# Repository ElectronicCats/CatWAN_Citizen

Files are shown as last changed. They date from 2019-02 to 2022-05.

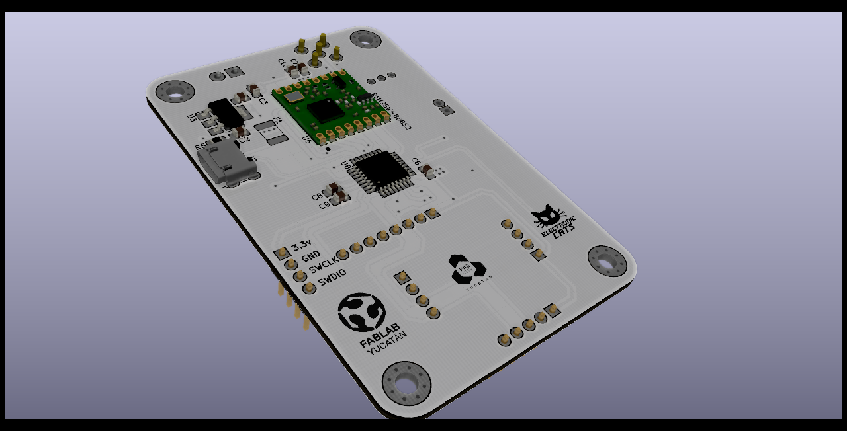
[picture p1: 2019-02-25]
Hardware/Citizen_Render_back.png

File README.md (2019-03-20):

# CatWAN Citizen Sensor Board

LoRa Smart city sensor, based on open hardware and free software, generating and sharing real open data on air pollution, acoustics and many more, compatible with LoRa and LoRaWAN.

## Sensor list

|Metric|Units|Sensor|
|-|:-:|:-:|
| **Atmospheric Pressure** | Pa | BME280 |
| **Air Temperature / Relative Humidity** | ºC / %rh | BME280|
| **CO, eCO2** | ppm |AMS CCS811|
| **Noise Level and Spectrum** | dBa |Microphone|
| **Ambient Light** | lx | Rohm BEML6075 |

## LICENSE
Firmware released under an GNU AGPL v3.0 license. See the LICENSE file for more information.

Hardware released under an CERN Open Hardware Licence v1.2. See the LICENSE_HARDWARE file for more information.

Designed by Electronic Cats.

Electronic Cats is a registered trademark, please do not use if you sell these PCBs.

Electronic Cats invests time and resources providing this open source design, please support Electronic Cats and open-source hardware by purchasing products from Electronic Cats!

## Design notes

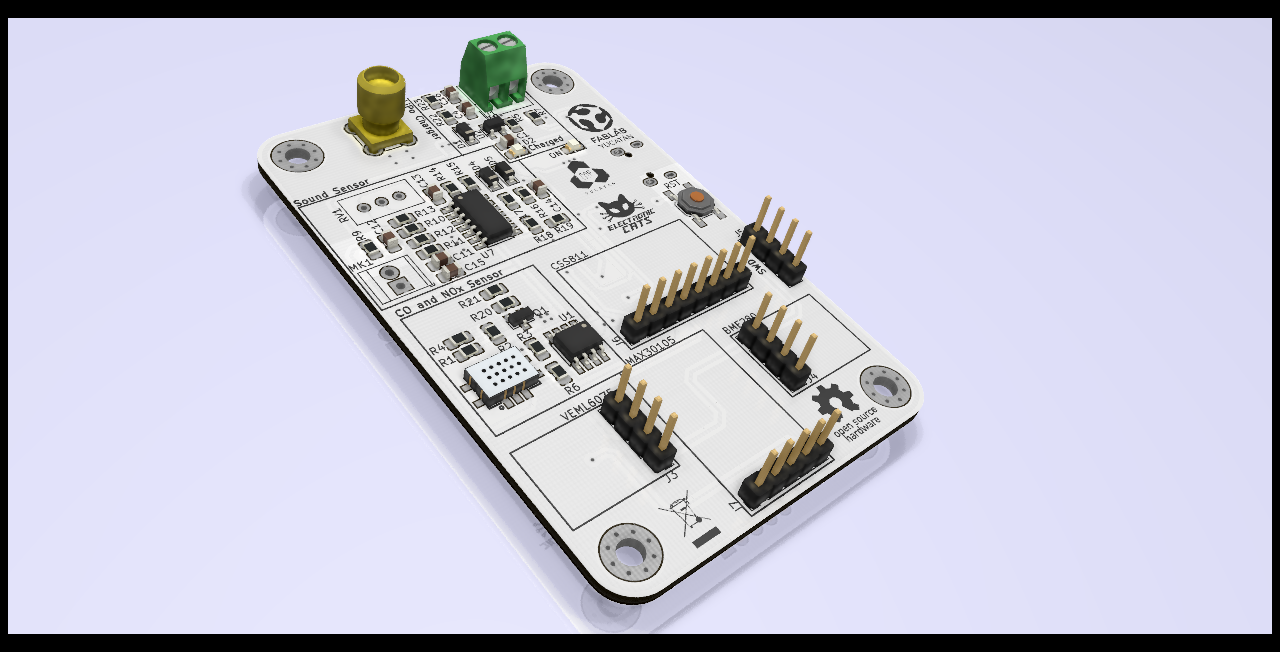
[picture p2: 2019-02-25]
Hardware/Citizen_Render_front.png

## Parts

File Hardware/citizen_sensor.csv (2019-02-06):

Item | Qty | Reference(s) | Value | manf#
1 | 1 | AE1 | Antenna_Shield | 977325
2 | 4 | C1, C2, C4, C5 | 10uf | 885012107004
3 | 5 | C3, C6, C7, C9,C15 | 0.1uf | 08056C104JAZ2A
4 | 3 | C8, C10, C11 | 1uf | CC0805KKX5R5BB105
5 | 2 | C12, C14 | 10uF | 885012107004
6 | 1 | C13 | 1uF | CC0805KKX5R5BB105
7 | 1 | D1 | D_Schottky | NRVB120VLSFT1G
8 | 1 | D2 | CHARGE | 150080VS75000
9 | 1 | D3 | ON | 150080SS75000
10 | 2 | D4, D5 | RB751S40T1G | NRVB120VLSFT1G
11 | 1 | F1 | Fuse | 0ZCG0030FF2C
13 | 1 | J2 | USB_B_Micro | 885012107004
17 | 1 | MK1 | Microphone | POM-3044P-R
18 | 1 | Q1 | 2N7002 | T2N7002AK,LM
19 | 2 | R1, R4 | 30 | CRCW080530R0FKEAC
20 | 1 | R2 | 36 | ERJ-6ENF36R0V
21 | 1 | R3 | 269 | ESR10EZPJ271
22 | 1 | R5 | 10k | ESR10EZPJ103
23 | 1 | R6 | 1 | RC0805FR-071R
24 | 2 | R7, R8 | 1k | ESR10EZPJ102
25 | 1 | R9 | 2.2K | RCG08052K20JNEA
26 | 2 | R10, R18 | 1K | ESR10EZPJ102
27 | 4 | R11, R12, R14, R17 | 10K | ESR10EZPJ103
28 | 1 | R13 | 100K | ERJ-6ENF1003V
29 | 1 | R15 | 22K | CRGP0805F22K
30 | 2 | R16, R19 | 100 | ESR10EZPJ101
31 | 1 | R20 | 66.5k | ERJ-6ENF6652V
32 | 1 | R21 | 66.5 | CRCW080566R5FKEA
33 | 1 | RV1 | 100K GAIN | 3362P-1-104LF
35 | 1 | U1 | TLC2272 | TLC2272CD
36 | 1 | U2 | MCP73831 | MCP73831T-5ACI/OT
37 | 1 | U3 | AP2114 | AP2114H-3.3TRG1
38 | 1 | U4 | MICS-4514 | MICS-4514
40 | 1 | U7 | LM324 | LM324DR
41 | 1 | U8 | ATSAMD21E18A-MU | ATSAMD21E15B-AUT

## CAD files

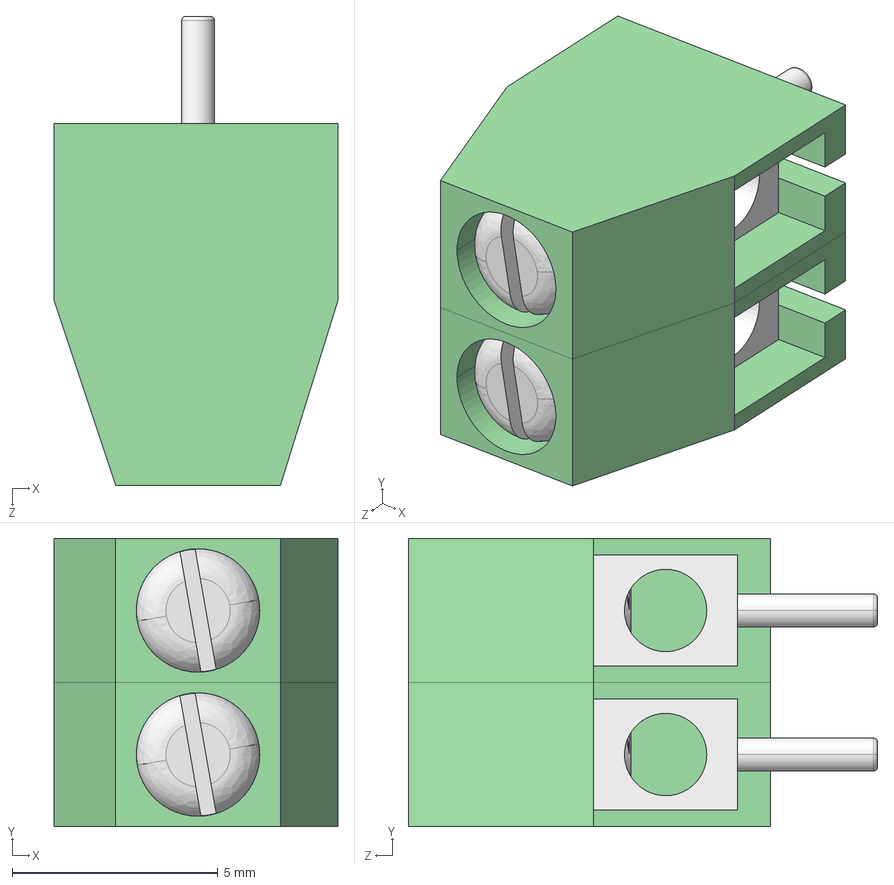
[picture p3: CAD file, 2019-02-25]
Hardware/3D/User Library-KF350-2P.STEP
6.90 x 7.00 x 11.4 mm
User Library-KF350-2P_KF850 Body x 2
User Library-KF350-2P_KF850 PIN x 2
User Library-KF350-2P_M2 Screw_91200A100 x 2

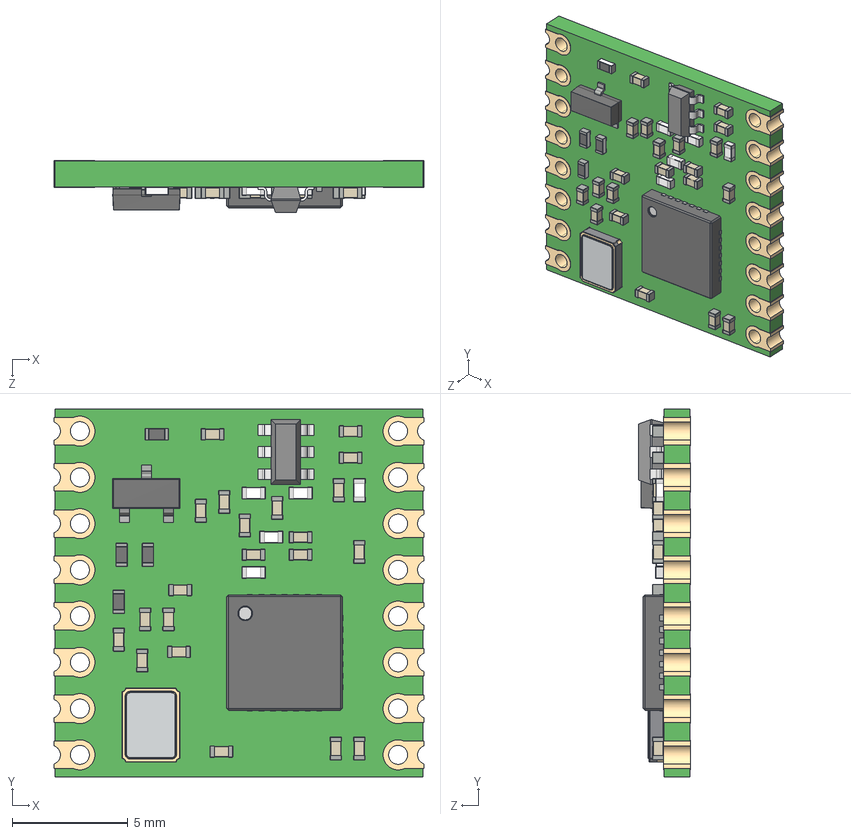
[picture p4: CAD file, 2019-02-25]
Hardware/3D/User Library-RFM96W.STEP
16.0 x 15.9 x 2.23 mm
User Library-RFM96W_Board
User Library-RFM96W_Cap0402 x 21
User Library-RFM96W_SW3dPS-inductor_0402_white x 5
User Library-RFM96W_SW3dPS-SOT-23-6
User Library-RFM96W_QFN28
User Library-RFM96W_TXC_7M
User Library-RFM96W_Res0402 x 4
User Library-RFM96W_User_Library-3-lead_sot23-3
User Library-RFM96W_Goldcontact x 16

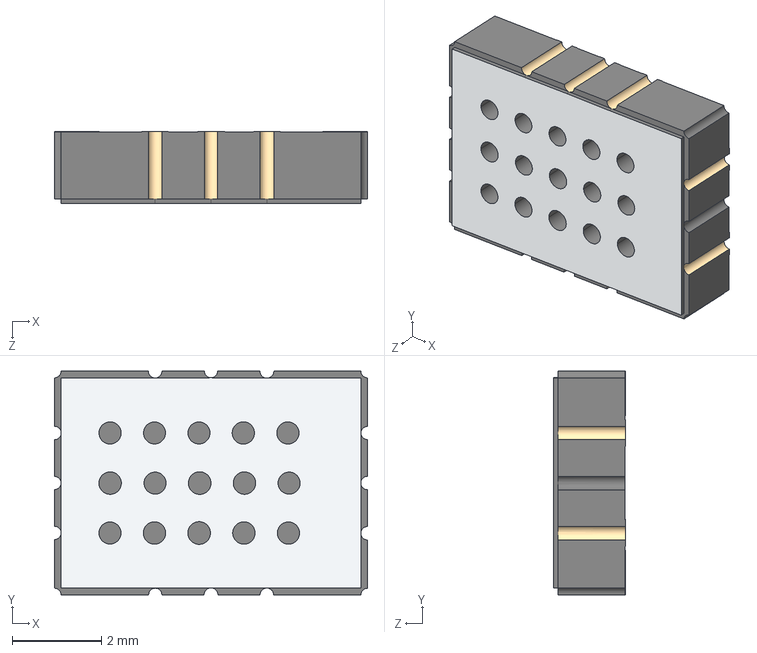
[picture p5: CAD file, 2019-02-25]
Hardware/3D/MICS-4514.STEP
7.00 x 5.00 x 1.61 mm

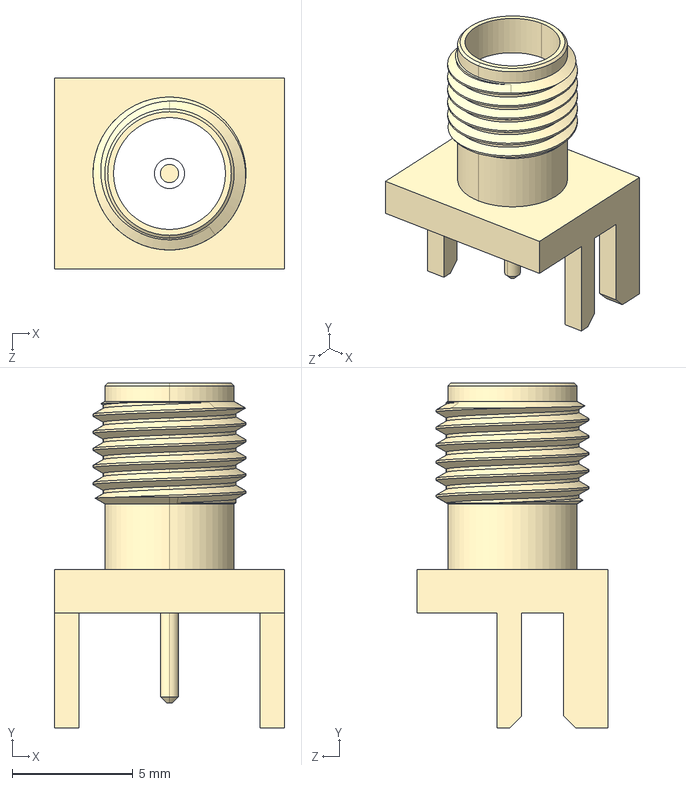
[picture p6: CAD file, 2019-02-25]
Hardware/3D/User Library-Johnson Components SMA - 50 Ohm Connectors 142-0701-801.STEP
9.52 x 14.3 x 7.92 mm

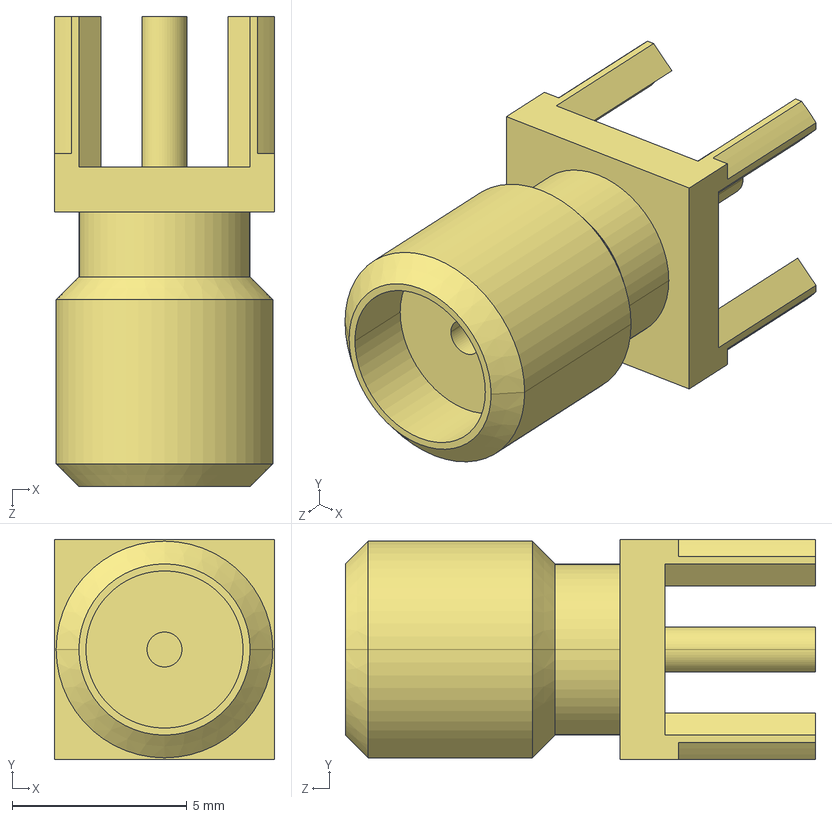
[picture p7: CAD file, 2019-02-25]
Hardware/3D/sma.STEP
6.31 x 6.31 x 13.4 mm

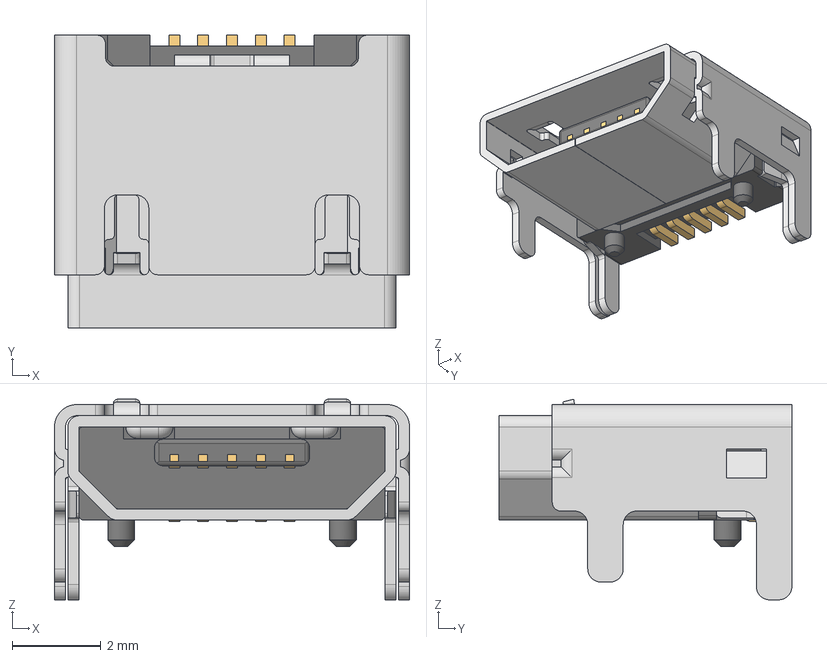
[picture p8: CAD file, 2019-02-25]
Hardware/3D/629105150521 (rev1).stp
8.00 x 6.60 x 4.52 mm
629105150521_Housing
629105150521_Pin1 x 4
629105150521_Pin2
629105150521_Shielding2
629105150521_Shielding

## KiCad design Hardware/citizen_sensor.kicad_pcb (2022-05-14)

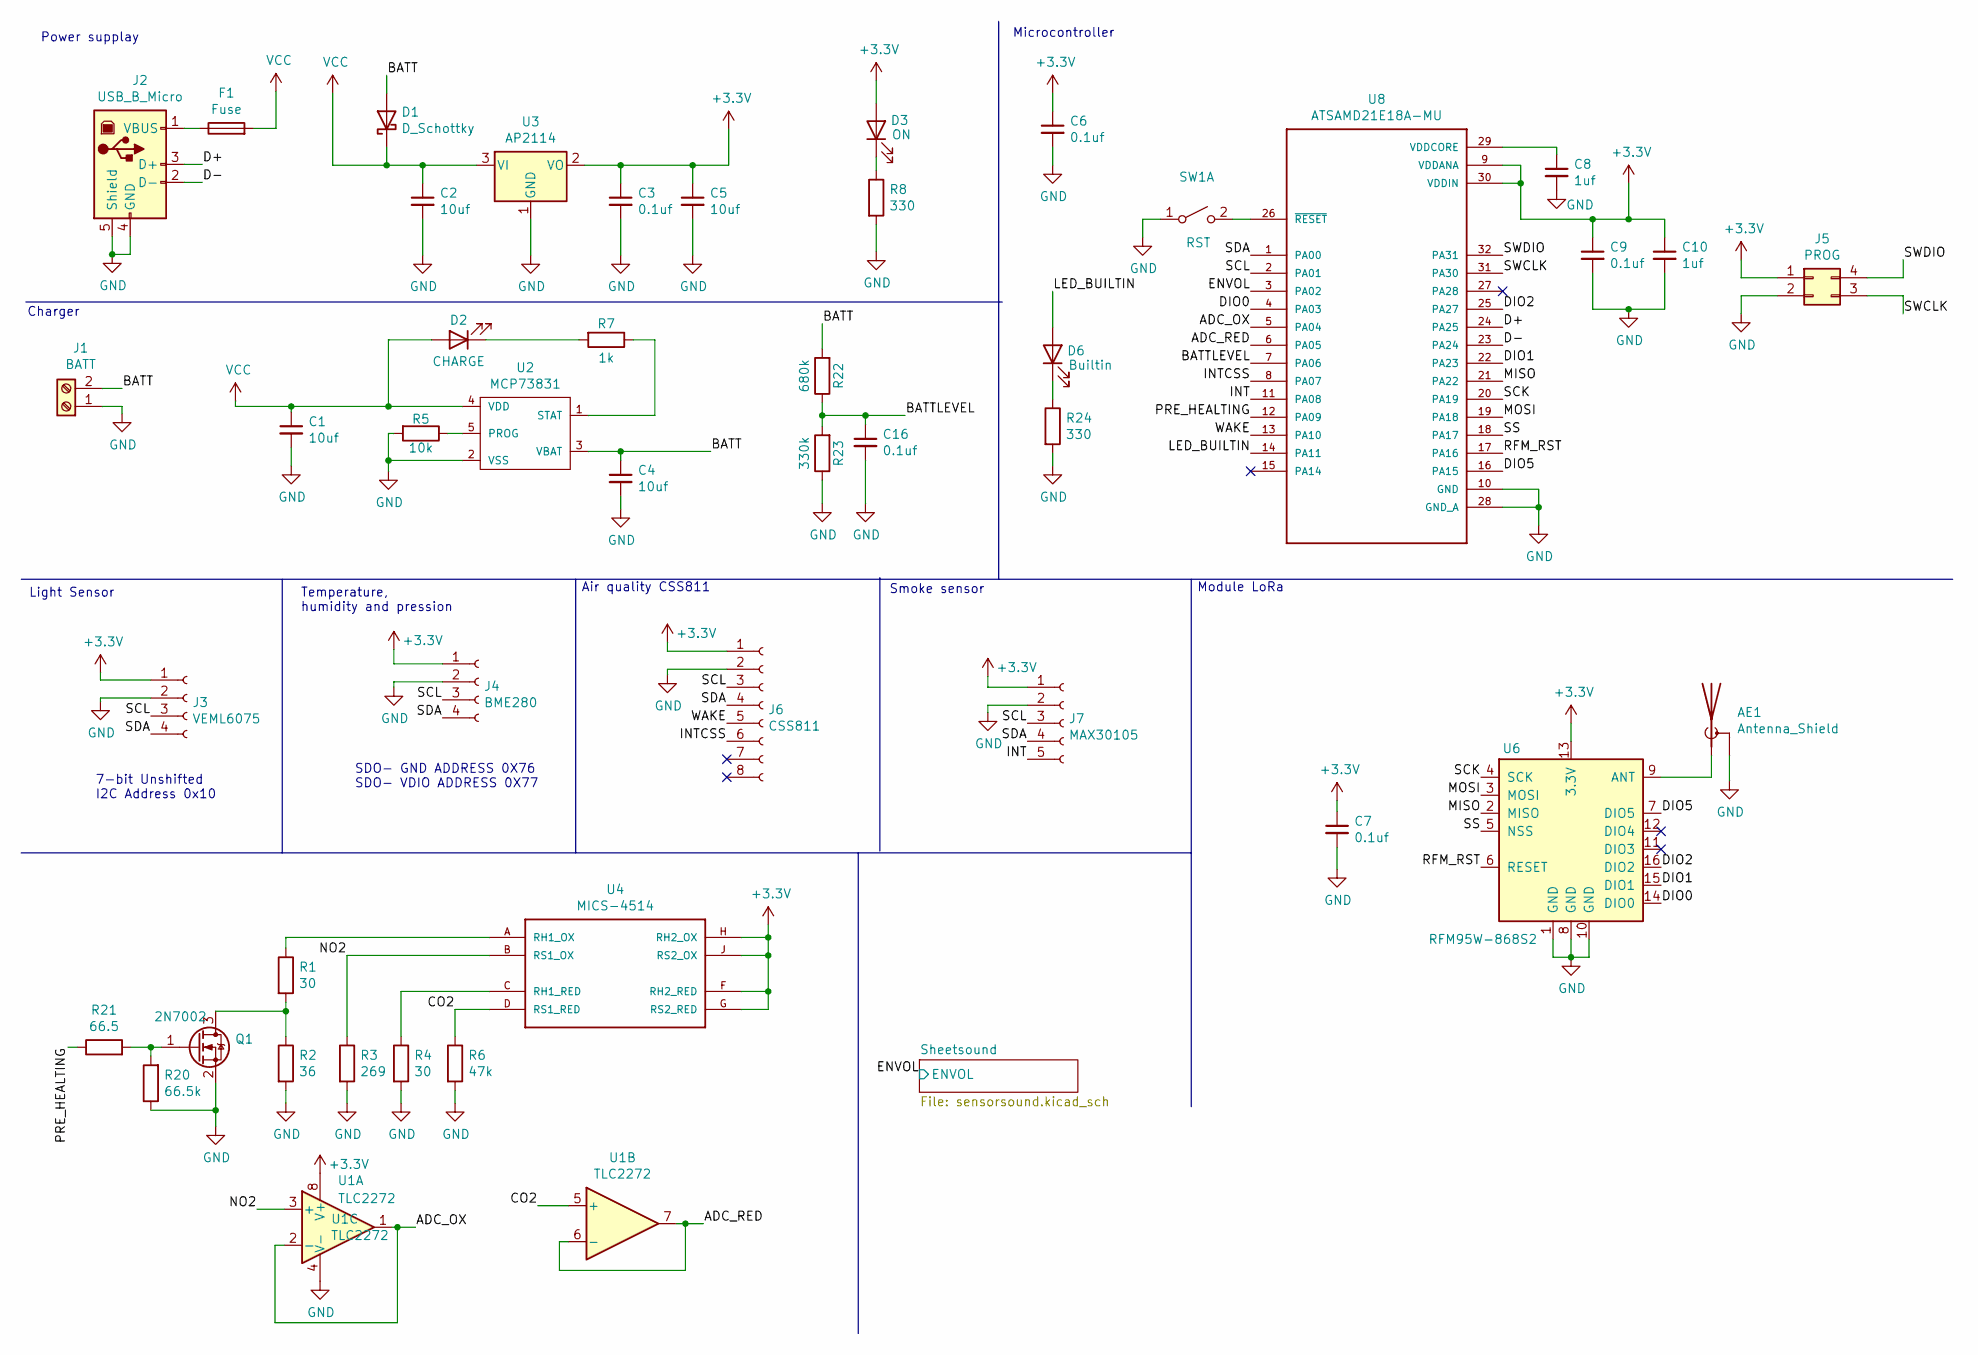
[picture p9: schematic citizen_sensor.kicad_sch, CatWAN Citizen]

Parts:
AE1: Antenna_Shield; AMPHENOL_901-144
C1, C2, C4, C5: 10uf; C_0805_2012Metric_Pad1.15x1.40mm_HandSolder
C3, C6, C7, C9, C16: 0.1uf; C_0805_2012Metric_Pad1.15x1.40mm_HandSolder
C8, C10: 1uf; C_0805_2012Metric_Pad1.15x1.40mm_HandSolder
D1: D_Schottky; D_SOD-123
D2: CHARGE; LED_0805_2012Metric_Castellated
D3: ON; LED_0805_2012Metric_Castellated
D6: Builtin; LED_0805_2012Metric_Castellated
F1: Fuse; Fuse_1812_4532Metric_Pad1.30x3.40mm_HandSolder
J1: BATT; TerminalBlock_4Ucon_1x02_P3.50mm_Vertical
J2: USB_B_Micro; USB_Micro-B_Wuerth_629105150521
J3: VEML6075; PinHeader_1x04_P2.54mm_Vertical
J4: BME280; PinHeader_1x04_P2.54mm_Vertical
J5: PROG; PinHeader_1x04_P2.54mm_Vertical
J6: CSS811; PinHeader_1x08_P2.54mm_Vertical
J7: MAX30105; PinHeader_1x05_P2.54mm_Vertical
Q1: 2N7002; SOT-23
R1, R4: 30; R_0805_2012Metric_Pad1.15x1.40mm_HandSolder
R2: 36; R_0805_2012Metric_Pad1.15x1.40mm_HandSolder
R3: 269; R_0805_2012Metric_Pad1.15x1.40mm_HandSolder
R5: 10k; R_0805_2012Metric_Pad1.15x1.40mm_HandSolder
R6: 47k; R_0805_2012Metric_Pad1.15x1.40mm_HandSolder
R7: 1k; R_0805_2012Metric_Pad1.15x1.40mm_HandSolder
R8, R24: 330; R_0805_2012Metric_Pad1.15x1.40mm_HandSolder
R20: 66.5k; R_0805_2012Metric_Pad1.15x1.40mm_HandSolder
R21: 66.5; R_0805_2012Metric_Pad1.15x1.40mm_HandSolder
R22: 680k; R_0805_2012Metric_Pad1.15x1.40mm_HandSolder
R23: 330k; R_0805_2012Metric_Pad1.15x1.40mm_HandSolder
SW1: RST; SW_SPST_TL3342
U1: TLC2272; SOIC-8_3.9x4.9mm_P1.27mm
U2: MCP73831; SOT-23-5
U3: AP2114; SOT-223-3_TabPin2
U4: MICS-4514; MICS_10-SMD
U6: RFM95W-868S2; RFM95W
U8: ATSAMD21E18A-MU; TQFP-32_7x7mm_P0.8mm

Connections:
+3V3: C3.1, C5.1, C6.1, C7.1, C9.1, C10.1, D3.2 (A), J3.1, J4.1, J5.1, J6.1, J7.1, U1.8 (V+), U3.2 (VO), U4.F (RH2_RED), U4.G (RS2_RED), U4.H (RH2_OX), U4.J (RS2_OX), U6.13 (3.3V), U8.9 (VDDANA), U8.30 (VDDIN); also elsewhere on the board
/ADC_OX: U1.1, U1.2 (-), U8.5 (PA04)
/ADC_RED: U1.6 (-), U1.7, U8.6 (PA05)
/BATT: C4.1, D1.2 (A), J1.2, R22.2, U2.3 (VBAT)
/BATTLEVEL: C16.1, R22.1, R23.2, U8.7 (PA06)
/CO2: R6.1, U1.5 (+), U4.D (RS1_RED)
/D+: J2.3 (D+), U8.24 (PA25)
/D-: J2.2 (D-), U8.23 (PA24)
/DIO0: U6.14 (DIO0), U8.4 (PA03)
/DIO1: U6.15 (DIO1), U8.22 (PA23)
/DIO2: U6.16 (DIO2), U8.25 (PA27)
/DIO5: U6.7 (DIO5), U8.16 (PA15)
/ENVOL: U8.3 (PA02); also elsewhere on the board
/INT: J7.5, U8.11 (PA08)
/INTCSS: J6.6, U8.8 (PA07)
/LED_BUILTIN: D6.2 (A), U8.14 (PA11)
/MISO: U6.2 (MISO), U8.21 (PA22)
/MOSI: U6.3 (MOSI), U8.19 (PA18)
/NO2: R3.1, U1.3 (+), U4.B (RS1_OX)
/PRE_HEALTING: R21.1, U8.12 (PA09)
/RFM_RST: U6.6 (RESET), U8.17 (PA16)
/SCK: U6.4 (SCK), U8.20 (PA19)
/SCL: J3.3, J4.3, J6.3, J7.3, U8.2 (PA01)
/SDA: J3.4, J4.4, J6.4, J7.4, U8.1 (PA00)
/SS: U6.5 (NSS), U8.18 (PA17)
/SWCLK: J5.3, U8.31 (PA30)
/SWDIO: J5.4, U8.32 (PA31)
/WAKE: J6.5, U8.13 (PA10)
GND: AE1.2 (Shield), C1.2, C2.2, C3.2, C4.2, C5.2, C6.2, C7.2, C8.2, C9.2, C10.2, C16.2, J1.1, J2.4 (GND), J2.5 (Shield), J3.2, J4.2, J5.2, J6.2, J7.2, Q1.2 (S), R2.2, R3.2, R4.2, R5.2, R6.2, R8.2, R20.1, R23.1, R24.2, SW1.1 (A), U1.4 (V-), U2.2 (VSS), U3.1 (GND), U6.1 (GND), U6.8 (GND), U6.10 (GND), U8.10 (GND), U8.28 (GND_A); also elsewhere on the board
unnamed: AE1.1 (A), U6.9 (ANT)
unnamed: C8.1, U8.29 (VDDCORE)
unnamed: D2.1 (K), R7.2
unnamed: D3.1 (K), R8.1
unnamed: D6.1 (K), R24.1
unnamed: F1.1, J2.1 (VBUS)
unnamed: Q1.1 (G), R20.2, R21.2
unnamed: Q1.3 (D), R1.2, R2.1
unnamed: R1.1, U4.A (RH1_OX)
unnamed: R4.1, U4.C (RH1_RED)
unnamed: R5.1, U2.5 (PROG)
unnamed: R7.1, U2.1 (STAT)
unnamed: SW1.2 (B), U8.26 (~RESET)
VCC: C1.1, C2.1, D1.1 (K), D2.2 (A), F1.2, U2.4 (VDD), U3.3 (VI)

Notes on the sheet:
Module LoRa
Microcontroller
Air quality CSS811
Smoke sensor
Power supplay
7-bit Unshifted I2C Address 0x10
Charger
Light Sensor
Temperature, humidity and pression
SDO- GND ADDRESS 0X76 SDO- VDIO ADDRESS 0X77

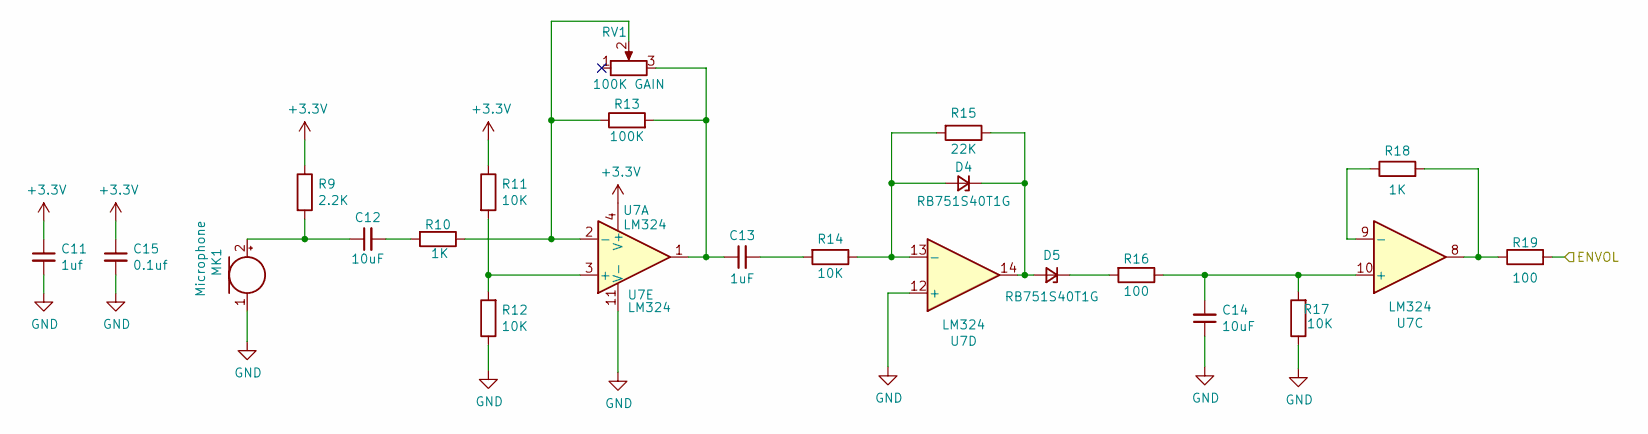
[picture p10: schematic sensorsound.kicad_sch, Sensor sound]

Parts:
C11: 1uf; C_0805_2012Metric_Pad1.15x1.40mm_HandSolder
C12, C14: 10uF; C_0805_2012Metric_Pad1.15x1.40mm_HandSolder
C13: 1uF; C_0805_2012Metric_Pad1.15x1.40mm_HandSolder
C15: 0.1uf; C_0805_2012Metric_Pad1.15x1.40mm_HandSolder
D4, D5: RB751S40T1G; D_SOD-123
MK1: Microphone; TerminalBlock_TE_282834-2_1x02_P2.54mm_Horizontal
R9: 2.2K; R_0805_2012Metric_Pad1.15x1.40mm_HandSolder
R10, R18: 1K; R_0805_2012Metric_Pad1.15x1.40mm_HandSolder
R11, R12, R14, R17: 10K; R_0805_2012Metric_Pad1.15x1.40mm_HandSolder
R13: 100K; R_0805_2012Metric_Pad1.15x1.40mm_HandSolder
R15: 22K; R_0805_2012Metric_Pad1.15x1.40mm_HandSolder
R16, R19: 100; R_0805_2012Metric_Pad1.15x1.40mm_HandSolder
RV1: 100K GAIN; Potentiometer_Bourns_3386P_Vertical
U7: LM324; SOIC-14_3.9x8.7mm_P1.27mm

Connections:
+3V3: C11.1, C15.1, R9.1, R11.1, U7.4 (V+); also elsewhere on the board
/ENVOL: R19.2; also elsewhere on the board
GND: C11.2, C14.1, C15.2, MK1.1 (-), R12.1, R17.1, U7.11 (V-), U7.12 (+); also elsewhere on the board
unnamed: C12.1, MK1.2 (+), R9.2
unnamed: C12.2, R10.2
unnamed: C13.1, R13.2, RV1.3, U7.1
unnamed: C13.2, R14.2
unnamed: C14.2, R16.1, R17.2, U7.10 (+)
unnamed: D4.1 (K), D5.2 (A), R15.1, U7.14
unnamed: D4.2 (A), R14.1, R15.2, U7.13 (-)
unnamed: D5.1 (K), R16.2
unnamed: R10.1, R13.1, RV1.2, U7.2 (-)
unnamed: R11.2, R12.2, U7.3 (+)
unnamed: R18.1, U7.9 (-)
unnamed: R18.2, R19.1, U7.8

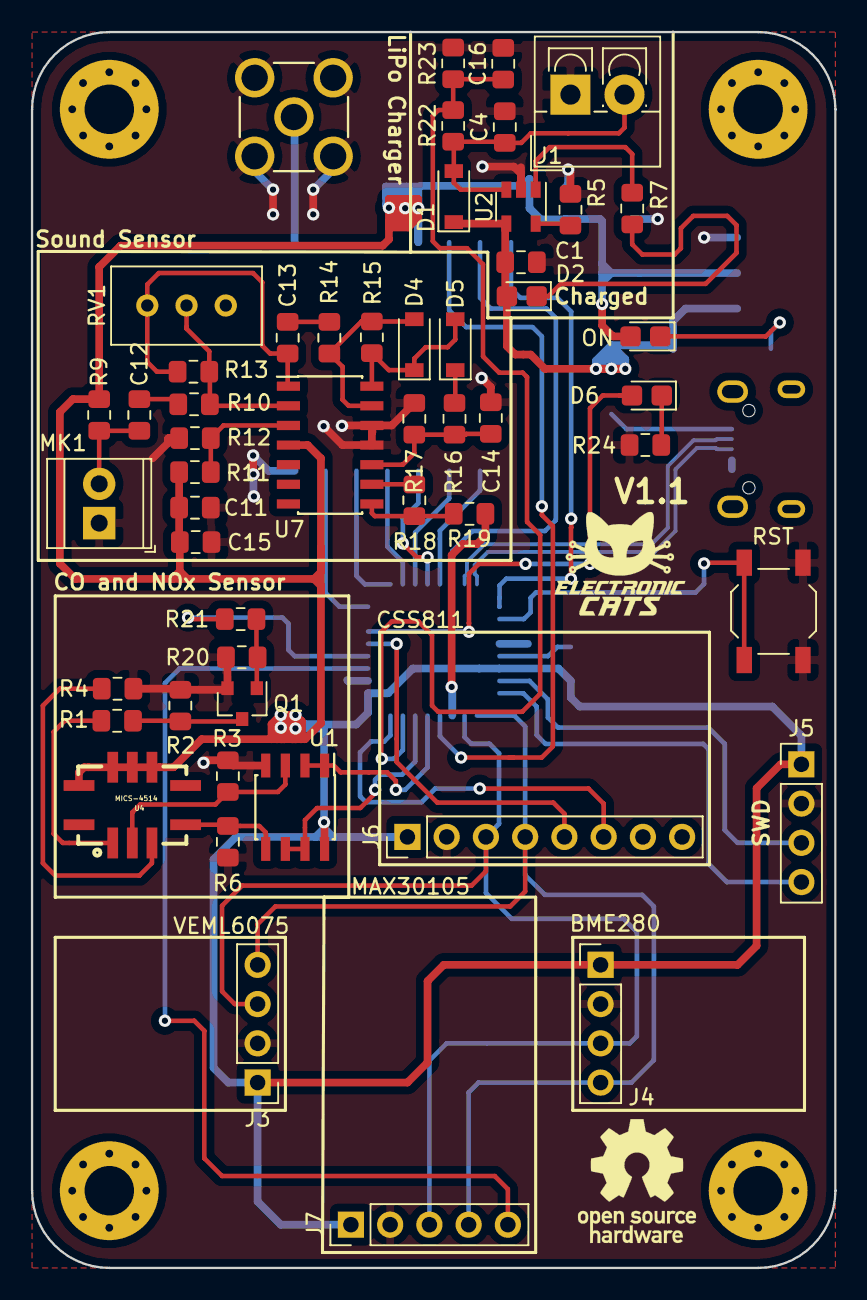
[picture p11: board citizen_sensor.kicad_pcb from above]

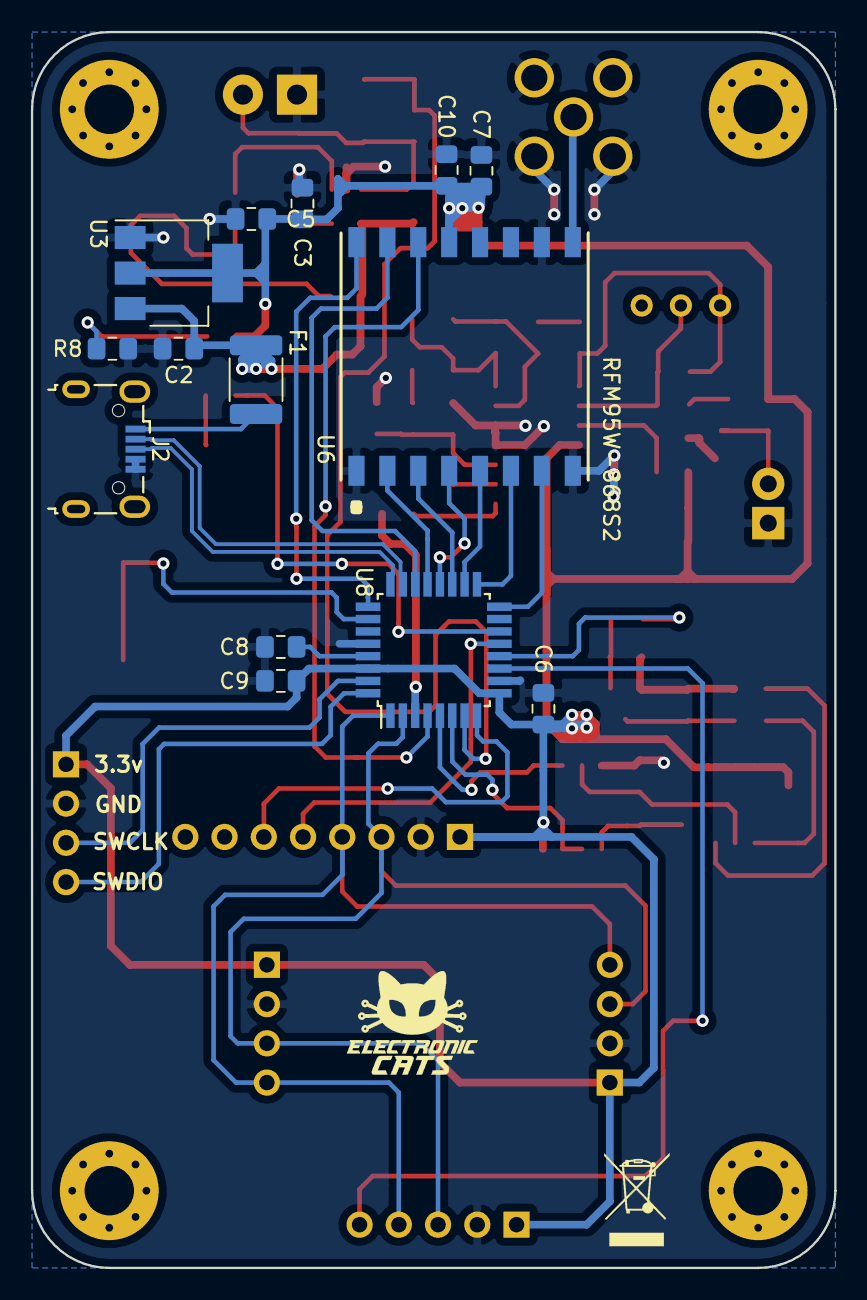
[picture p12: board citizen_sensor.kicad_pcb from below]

Board: 2 copper layers, 52.0 x 80.0 mm, 66 parts (14 on the bottom side), 55 nets.

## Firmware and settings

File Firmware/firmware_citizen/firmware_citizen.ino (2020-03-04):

/*******************************************************************************
  Created by: Eduardo Contreras @ Electronic Cats 2019
              Rocio Rodriguez @ Electronic Cats 2019
              Andres Sabas @ Electronic Cats 2020
 
  Example for the CITIZEN board
    In this example you can send:
    TEMPERATURE, HUMINIDY AND PRESSURE sensor information read by the BME280 
    CO and NO2 levels sensor informationread by the MICS4514 
    CO2 levels sensor information read by the CSS811 
    VEML6075
    Sound Sensor embedded
    
  Example
 *******************************************************************************/
#include <lorawan.h>
#include <CayenneLPP.h>
#include <Wire.h>
#include "Adafruit_CCS811.h"
#include "SparkFunBME280.h"
#include <SparkFun_VEML6075_Arduino_Library.h>

#define _USE_BME_
#define _USE_CSS_
#define _USE_MICS_
#define _USE_VME_
//#define _USE_SOUND_
//#define DEBUG

#ifdef _USE_BME_ 
  BME280 BME; 
#endif

#ifdef _USE_CSS_ //pregunta si de definio el sensor CCS811
  Adafruit_CCS811 ccs;
#endif

#ifdef _USE_VME_ 
  VEML6075 uv; 
  // Calibration constants:
  // Four gain calibration constants -- alpha, beta, gamma, delta -- can be used to correct the output in
  // reference to a GOLDEN sample. The golden sample should be calibrated under a solar simulator.
  // Setting these to 1.0 essentialy eliminates the "golden"-sample calibration
  const float CALIBRATION_ALPHA_VIS = 1.0; // UVA / UVAgolden
  const float CALIBRATION_BETA_VIS  = 1.0; // UVB / UVBgolden
  const float CALIBRATION_GAMMA_IR  = 1.0; // UVcomp1 / UVcomp1golden
  const float CALIBRATION_DELTA_IR  = 1.0; // UVcomp2 / UVcomp2golden

  // Responsivity:
  // Responsivity converts a raw 16-bit UVA/UVB reading to a relative irradiance (W/m^2).
  // These values will need to be adjusted as either integration time or dynamic settings are modififed.
  // These values are recommended by the "Designing the VEML6075 into an application" app note for 100ms IT
  const float UVA_RESPONSIVITY = 0.00110; // UVAresponsivity
  const float UVB_RESPONSIVITY = 0.00125; // UVBresponsivity

  // UV coefficients:
  // These coefficients
  // These values are recommended by the "Designing the VEML6075 into an application" app note
  const float UVA_VIS_COEF_A = 2.22; // a
  const float UVA_IR_COEF_B  = 1.33; // b
  const float UVB_VIS_COEF_C = 2.95; // c
  const float UVB_IR_COEF_D  = 1.75; // d
#endif

#ifdef _USE_SOUND_ 
#define N 5
  float filtered;
  float vals[N];

  const double dBAnalogQuiet = 10; // envelope - calibrated value from analog input (48 dB equivalent)
  const double dBAnalogModerate = 15;
  const double dBAnalogLoud = 30;
  int count;

float calculateDecibels(int x, char c)
{
  float decibelsCalculated;
  
    if (c == 'q')
      decibelsCalculated = 20 * log10(x/dBAnalogQuiet);
    if (c == 'm')
      decibelsCalculated = 20 * log10(x/dBAnalogModerate);
    if (c == 'l')
      decibelsCalculated = 20 * log10(x/dBAnalogLoud);  
      
  return (decibelsCalculated);
}
#endif

CayenneLPP lpp(51);

//ABP Credentials 
const char *devAddr = "00000000";
const char *nwkSKey = "00000000000000000000000000000000";
const char *appSKey = "00000000000000000000000000000000";

unsigned long previousMillis = 0;  // will store last time message sent
const unsigned long interval = 30000;    // 10 s interval to send message

// Pin mapping for RFM9X
const sRFM_pins RFM_pins = {
  .CS = SS,
  .RST = RFM_RST,
  .DIO0 = RFM_DIO0,
  .DIO1 = RFM_DIO1,
  .DIO2 = RFM_DIO2,
  .DIO5 = RFM_DIO5,
};


void setup() {
  Serial.begin(115200);
  #ifdef DEBUG
    while(!Serial);
  #endif
  Serial.println(F("[INFO] LoRa Demo Node 1 Demonstration"));

   if(!lora.init()){
    Serial.println("RFM95 not detected");
    delay(5000);
    return;
  }
  
  #ifdef _USE_BME_
  Wire.begin();
  BME.setI2CAddress(0x76); //Connect to a second sensor
  if(BME.beginI2C() == false) Serial.println("Sensor BME280 connect failed");
  #endif

  #ifdef _USE_CSS_
  Serial.println("[INFO] CCS811 in use");
  pinMode(10, OUTPUT);
  digitalWrite(10, LOW);
  
  if(!ccs.begin()){
    Serial.println("[INFO] Failed to start sensor CSS811! Please check your wiring.");
    while(1);
    //calibrate temperature sensor
    while(!ccs.available());
    float temp = ccs.calculateTemperature();
    ccs.setTempOffset(temp - 25.0);
  }
  #endif

  #ifdef _USE_MICS_
  pinMode(9,OUTPUT);
  analogReadResolution(12);
  Serial.println("[INFO] Pre heating MICS");
  digitalWrite(9, HIGH);
  Serial.println("[INFO] heating MICS");
  Serial.println("[INFO] Pre heating done MICS");
  digitalWrite(9, LOW);
  #endif

    #ifdef _USE_VME_
  if (!uv.begin())
  {
    Serial.println("Unable to communicate with VEML6075.");
    while (1);
  }

  // Integration time and high-dynamic values will change the UVA/UVB sensitivity. That means
  // new responsivity values will need to be measured for every combination of these settings.
  uv.setIntegrationTime(VEML6075::IT_100MS);
  uv.setHighDynamic(VEML6075::DYNAMIC_NORMAL);
  #endif

  // Set LoRaWAN Class change CLASS_A or CLASS_C
  lora.setDeviceClass(CLASS_A);

  // Set Data Rate
  lora.setDataRate(SF8BW125);

  // set channel to random
  lora.setChannel(MULTI);
  
  // Put ABP Key and DevAddress here
  lora.setNwkSKey(nwkSKey);
  lora.setAppSKey(appSKey);
  lora.setDevAddr(devAddr);
}

void loop() {
  if(millis() - previousMillis > interval) {
    getInfoAndSend();
    previousMillis = millis();
  }
  // Check Lora RX
  lora.update();
}

void getInfoAndSend() {
  int chan = 0;
  Serial.println(F("[INFO] Collecting info"));
  lpp.reset();

  #ifdef _USE_BME_  //Temperature/HUMIDITY/PRESSURE
    float temp = readTemp();
    Serial.print(F("[INFO] Temperature:")); 
    Serial.println(temp,2);
    lpp.addTemperature(chan++,temp);
    
    float humi = readhumi();
    Serial.print(F("[INFO] Humidity:")); 
    Serial.println(humi,2);
    lpp.addRelativeHumidity(chan++,humi);
    
    float pressu = readpress()/100;
    Serial.print(F("[INFO] Pressure hPa:")); 
    Serial.println(pressu);
    lpp.addBarometricPressure(chan++,pressu);
  #else
    chan=chan+3;
  #endif

  #ifdef _USE_CSS_  //CO2 and TVOC
    Serial.print("[INFO] CO2:"); 
    Serial.println(readCO2(),2);
    lpp.addAnalogInput(chan++,readCO2());
  #else
    chan++;
  #endif

  #ifdef _USE_MICS_  //CO and NO2
    Serial.print("[INFO] CO ppm:"); 
    Serial.println(readCO(),2);
    lpp.addAnalogInput(chan++,readCO());
   
    Serial.print("[INFO] NO2 ppm:"); 
    Serial.println(readNO2(),2);
    lpp.addAnalogInput(chan++,readNO2());
  #else
    chan=chan+2;
  #endif

    #ifdef _USE_VME_  //Temperature/HUMIDITY/PRESSURE
    Serial.print("[INFO] UV indice:"); 
    Serial.println(readUV(),2);
    lpp.addAnalogInput(chan++,readUV());
  #else
    chan++;
  #endif

   #ifdef _USE_SOUND_  //Sound dB
    float  DB= readDB();
    Serial.print("[INFO] DB indice:"); 
    Serial.println(DB,2);
    lpp.addAnalogInput(chan++,DB);
   #else
    chan++;
  #endif

  lpp.addDigitalInput(chan++,readBattery());
  // print out the value you read:
  Serial.print("[INFO] Battery:");
  Serial.print(readBattery());
  Serial.println("V");
  
  #ifdef DEBUG  //Battery
  Serial.println(lpp.getSize());
  Serial.println(F("[LoRa] Start Radio TX"));
  #endif
  
  lora.sendUplink((char*)lpp.getBuffer(), lpp.getSize(), 0);
  }

// hace la funcion si esta definido el objeto del sensor, si no no toma en cuenta para compilar
#ifdef _USE_BME_  
float readTemp(void) {
  float temperature = BME.readTempC();
  return temperature;
}

float readhumi(void) {
  float humidity = BME.readFloatHumidity();
  return humidity;
}

float readpress(void) {
  float Pressure = BME.readFloatPressure();
  return Pressure;
}
#endif

#ifdef _USE_CSS_  
float readCO2(void) {
    if (ccs.available()) {
    if (!ccs.readData()) {
    float co2 = ccs.geteCO2();
    float tvoc = ccs.getTVOC();
    return co2;
    }
    else {
      Serial.println("ERROR reading CCS811!");
      while (1);
    }
}
}
#endif

#ifdef _USE_MICS_  
  float readCO(void) {
    int co=analogRead(A1);
    //Convert to voltaje
    float vco=(3.3*co)/4096;
    //Convert to resist
    float rco=47000*((3.3-vco)/vco);//load resistor in red 1ohm
    //Convert to indicator concentration
    float conCO= 47000/rco;
    //Calculo de particulas por millon 
    float ppmCO=(4.4138*pow(conCO,-1.178));
    return ppmCO;
    }
  
  float readNO2(void) {
    int no2=analogRead(A2);
    float vno2=(3.3*no2)/4096;
   //Convert to resist
    float rno2=270*((3.3-vno2)/vno2);//load resistor in ox 270ohm
   //Convert to indicator concentration
    float conNO2= 270/rno2;
   //Calculo de particulas por millon 
    float ppmNO2= ((-0.0003*(conNO2*conNO2))+(0.1626*conNO2)-0.0217);
  return ppmNO2;
  }
#endif


#ifdef _USE_VME_  
float readUV(void) {
  uint16_t rawA, rawB, visibleComp, irComp;
  float uviaCalc, uvibCalc, uvia, uvib, uvi;

  // Read raw and compensation data from the sensor
  rawA = uv.rawUva();
  rawB = uv.rawUvb();
  visibleComp = uv.visibleCompensation();
  irComp = uv.irCompensation();

  // Calculate the simple UVIA and UVIB. These are used to calculate the UVI signal.
  uviaCalc = (float)rawA - ((UVA_VIS_COEF_A * CALIBRATION_ALPHA_VIS * visibleComp) / CALIBRATION_GAMMA_IR)
                  - ((UVA_IR_COEF_B  * CALIBRATION_ALPHA_VIS * irComp) /  CALIBRATION_DELTA_IR);
  uvibCalc = (float)rawB - ((UVB_VIS_COEF_C * CALIBRATION_BETA_VIS * visibleComp) / CALIBRATION_GAMMA_IR)
                  - ((UVB_IR_COEF_D  * CALIBRATION_BETA_VIS * irComp) /  CALIBRATION_DELTA_IR);

  // Convert raw UVIA and UVIB to values scaled by the sensor responsivity
  uvia = uviaCalc * (1.0 / CALIBRATION_ALPHA_VIS) * UVA_RESPONSIVITY;
  uvib = uvibCalc * (1.0 / CALIBRATION_BETA_VIS) * UVB_RESPONSIVITY;

  // Use UVIA and UVIB to calculate the average UVI:
  uvi = (uvia + uvib) / 2.0;
  return uvi;
}
#endif

#ifdef _USE_SOUND_  
 float readDB(void) {
  int value=0, i;
  float decibelsValueQuiet = 55;//49.5;//float decibelsValueQuiet = 49.5;
  float decibelsValueModerate = 70;//65;
  float decibelsValueLoud = 85;
  float valueDb;
  float sum=0;
  
  value = analogRead(A0);
  
  if (value <= 15)
  {
    decibelsValueQuiet += calculateDecibels(value, 'q');
    valueDb = decibelsValueQuiet; 
  }
  else if ((value > 15) && ( value < 23) )
  {
    decibelsValueModerate += calculateDecibels(value, 'm');
    valueDb = decibelsValueModerate;
  }
  else if(value >= 23)
  {
    decibelsValueLoud += calculateDecibels(value, 'l');
    valueDb = decibelsValueLoud;
  }

  for (int i = N-1 ; i>0 ; i--)
  {
    vals[i]=vals[i-1];  
  }
  vals[0]=valueDb;
  
  for(int i=0 ; i<N ; i++)
  {
    sum=sum+vals[i];
  }
  filtered = sum/N;
  return filtered;
}
#endif
int readBattery(){
  // read the input on analog pin 0:
  int sensorValue = analogRead(A3);
  // Convert the analog reading (which goes from 0 - 1023) to a voltage (0 - 4.3V):
  //float VBat = sensorValue * (3.7 / 4095.0);
  return sensorValue;
}

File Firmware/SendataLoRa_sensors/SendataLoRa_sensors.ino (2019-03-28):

/*******************************************************************************
  Created by Eduardo Contreras @ Electronic Cats 2019
  Based on Copyright (c) 2015 Thomas Telkamp and Matthijs Kooijman
  PLEASE REFER TO THIS LMIC LIBRARY https://github.com/things-nyc/arduino-lmic
  
  Example for the TTGO board
  In this example you can send Ultrasonic sensor information or a temperature 
  read by the DHT22  
  Example
 *******************************************************************************/
#include <lmic.h>
#include <hal/hal.h>
#include <SPI.h>
#include <CayenneLPP.h>
#include <Wire.h>
#include "Adafruit_CCS811.h"

#include "SparkFunBME280.h"


#define _USE_BME_//DEFINE BME280
//#define _USE_CSS_
#define _USE_MICS_

#ifdef _USE_BME_ //pregunta si de definio el sensor MICS
  BME280 mySensor; //Uses I2C address 0x76 (jumper closed)
#endif

#ifdef _USE_CSS_ //pregunta si de definio el sensor MICS
  Adafruit_CCS811 ccs;
#endif

#ifdef _USE_MICS_ //pregunta si de definio el sensor MICS
   //analog read
    int co=0;
    int no2=0;

   //Value voltaje
    float vco=0;
    float vno2=0;

   //Value resistencia
    float rco=0;
    float rno2=0;

   //Value Rs/Ro
    float conCO=0;
    float conNO2=0;

   //cálculo de ppm 
    double ppmCO=0;
    double ppmNO2=0;
#endif

#define debugSerial Serial


CayenneLPP lpp(51);

static const PROGMEM u1_t NWKSKEY[16] ={ 0xCB, 0x38, 0x58, 0x79, 0x40, 0x72, 0x1F, 0x4A, 0x8A, 0xE6, 0x4E, 0x49, 0xE7, 0x99, 0xE0, 0x7A };
static const u1_t PROGMEM APPSKEY[16] ={ 0x4A, 0x4D, 0xE1, 0xF4, 0x78, 0x7B, 0x41, 0xE4, 0x0B, 0x64, 0x17, 0x16, 0x35, 0x5F, 0xF2, 0xF3 };
static const u4_t DEVADDR =0x26021E3F;

void os_getArtEui (u1_t* buf) { }
void os_getDevEui (u1_t* buf) { }
void os_getDevKey (u1_t* buf) { }

static osjob_t sendjob;//asignar tiempos a trabajos

// Schedule TX every this many seconds (might become longer due to duty
// cycle limitations).
const unsigned TX_INTERVAL = 10;
unsigned long previousMillis = 0;

// Pin mapping for RFM9X
const lmic_pinmap lmic_pins = {
  .nss = SS, 
  .rxtx = LMIC_UNUSED_PIN,
  .rst = RFM_RST,
  .dio = {/*dio0*/ RFM_DIO0, /*dio1*/RFM_DIO1, /*dio2*/ RFM_DIO2}
};

void debug_char(u1_t b) {
  debugSerial.write(b);
}

void debug_hex (u1_t b) {
  debug_char("0123456789ABCDEF"[b >> 4]);
  debug_char("0123456789ABCDEF"[b & 0xF]);
}

void debug_buf (const u1_t* buf, u2_t len) {
  while (len--) {
    debug_hex(*buf++);
    debug_char(' ');
  }
  debug_char('\r');
  debug_char('\n');
}

void onEvent (ev_t ev) {
  switch (ev) {
    case EV_TXCOMPLETE:

      // indicating radio TX complete
      digitalWrite(LED_BUILTIN, LOW);

      debugSerial.println(F("[LMIC] Radio TX complete (included RX windows)"));
      if (LMIC.txrxFlags & TXRX_ACK)
        debugSerial.println(F("[LMIC] Received ack"));
      if (LMIC.dataLen) {
        debugSerial.print(F("[LMIC] Received "));
        debugSerial.print(LMIC.dataLen);
        debugSerial.println(F(" bytes of payload"));
        debug_buf(LMIC.frame + LMIC.dataBeg, LMIC.dataLen);
      }
      break;

    default:

      break;
  }
}

void do_send(osjob_t* j, uint8_t *mydata1, uint16_t len) {
  // Check if there is not a current TX/RX job running
  if (LMIC.opmode & OP_TXRXPEND) {
    debugSerial.println(F("[LMIC] OP_TXRXPEND, not sending"));
  } else {
    // Prepare upstream data transmission at the next possible time
    LMIC_setTxData2(1, mydata1, len, 0);
  }
}

void setup() {
  debugSerial.begin(115200);
  while(!Serial);
  debugSerial.println(F("[INFO] LoRa Demo Node 1 Demonstration"));

  pinMode(LED_BUILTIN,OUTPUT);

  #ifdef _USE_BME_
  Wire.begin();
  mySensor.setI2CAddress(0x76); //Connect to a second sensor
  if(mySensor.beginI2C() == false) Serial.println("Sensor connect failed");
  #endif

    #ifdef _USE_CSS_
  Serial.println("CCS811 test");
  pinMode(10, OUTPUT);
  digitalWrite(10, LOW);
  
  if(!ccs.begin()){
    Serial.println("Failed to start sensor! Please check your wiring.");
    while(1);
     //calibrate temperature sensor
  while(!ccs.available());
  float temp = ccs.calculateTemperature();
  ccs.setTempOffset(temp - 25.0);
  }
  #endif

  #ifdef _USE_MICS_
  pinMode(9,OUTPUT);
  Serial.println("pre heating");
  digitalWrite(9, HIGH);
  //delay (30000);
  Serial.println("pre heating done");
  digitalWrite(9, LOW);
  #endif
  
  os_init();
  LMIC_reset();

  uint8_t appskey[sizeof(APPSKEY)];
  uint8_t nwkskey[sizeof(NWKSKEY)];
  memcpy_P(appskey, APPSKEY, sizeof(APPSKEY));
  memcpy_P(nwkskey, NWKSKEY, sizeof(NWKSKEY));

  LMIC_setSession (0x1, DEVADDR, nwkskey, appskey);
  
  for (int channel=0; channel<72; ++channel) {
      LMIC_disableChannel(channel);
    }
      
      // TTN
      LMIC_enableChannel(8);
      LMIC_enableChannel(9);
      LMIC_enableChannel(10);  //904.3Mhz used for monochannel Gw
      LMIC_enableChannel(11);
      LMIC_enableChannel(12);
      LMIC_enableChannel(13);
      LMIC_enableChannel(14);
      LMIC_enableChannel(15);
      LMIC_enableChannel(65); 
   
  
    /*
      //SubBand_6
      LMIC_enableChannel(48);
      LMIC_enableChannel(49);
      LMIC_enableChannel(50);
      LMIC_enableChannel(51);
      LMIC_enableChannel(52);
      LMIC_enableChannel(53);
      LMIC_enableChannel(54);
      LMIC_enableChannel(55);
      LMIC_enableChannel(70);
  */
  LMIC_setLinkCheckMode(0);
  LMIC_setAdrMode(false);
  LMIC_setDrTxpow(DR_SF7, 14); //SF7

  previousMillis = millis();

}

void loop() {
  if (millis() > previousMillis + TX_INTERVAL * 1000) { //Start Job at every TX_INTERVAL*1000
    getInfoAndSend();
    previousMillis = millis();
  }
  os_runloop_once();
}

void getInfoAndSend() {
  int chan = 0;
  debugSerial.println(F("[INFO] Collecting info"));
  lpp.reset();

    #ifdef _USE_BME_  //Temperature/HUMIDITY/PRESSURE
    float temp = readTemp();
    debugSerial.print(F("[INFO] Temperature:")); 
    debugSerial.println(temp,2);
    lpp.addTemperature(chan++,temp);
    float humi = readhumi();
    debugSerial.print(F("[INFO] Humidity:")); 
    debugSerial.println(humi,2);
    lpp.addTemperature(chan++,humi);
    float pressu = readpress();
    debugSerial.print(F("[INFO] Pressure:")); 
    debugSerial.println(pressu,2);
    lpp.addTemperature(chan++,pressu);
  #endif

  #ifdef _USE_CSS_  //Temperature/HUMIDITY/PRESSURE
    float  CO2= readCO2();
    debugSerial.print(F("[INFO] Temperature:")); 
    debugSerial.println(CO2,2);
    lpp.addTemperature(chan++,CO2);
  #endif

  #ifdef _USE_MICS_  //Temperature/HUMIDITY/PRESSURE
    float  CO= readCO();
    debugSerial.print(F("[INFO] CO ppm:")); 
    debugSerial.println(CO,2);
    lpp.addTemperature(chan++,CO);
    float  no2= readNO2();
    debugSerial.print(F("[INFO] NO2 ppm:")); 
    debugSerial.println(no2,2);
    lpp.addTemperature(chan++,no2);
  #endif
  
  debugSerial.println(F("[LMIC] Start Radio TX"));
  digitalWrite(LED_BUILTIN, HIGH);
  do_send(&sendjob, lpp.getBuffer(), lpp.getSize());
  }
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

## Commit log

2019-01-23 microcontroller and power supply
    [citizen_sensor.kicad_pcb, citizen_sensor.sch]
2019-01-23 modulation LoRa
    [citizen_sensor.sch]
2019-01-24 values capacitor and resistor
    [citizen_sensor.sch]
2019-01-24 light sensor
    [citizen_sensor.sch]
2019-01-24 move files
    [citizen_sensor.kicad_pcb, citizen_sensor.sch]
2019-01-24 Atmospheric sensor
    [citizen_sensor.sch]
2019-01-25 add sound sensor
    [citizen_sensor.sch, sensorsound.sch]
2019-01-25 sound circuit ampli
    [citizen_sensor.sch, sensorsound.sch]
2019-01-26 sensor sound envolvent
    [citizen_sensor.sch, sensorsound.sch]
2019-01-26 change VCC with 3.3V sound sensor
    [citizen_sensor.sch, sensorsound.sch]
2019-01-28 add capacitor VDDCORE
    [citizen_sensor.sch]
2019-01-29 add com I2C to samd
    [citizen_sensor.sch]
2019-01-29 add signal sound to samd
    [citizen_sensor.sch]
2019-01-29 charger fix
    [citizen_sensor.sch]
2019-01-31 change BME280 brakeout
    [citizen_sensor.sch]
2019-01-31 add circuit MICS4514
    [citizen_sensor.sch]
2019-01-31 move data name
    [citizen_sensor.sch]
2019-02-01 change veml6075 to brakeout
    [citizen_sensor.sch, sensorsound.sch]
2019-02-05 ERC check
    [citizen_sensor.sch, sensorsound.sch]
2019-02-06 add fuse
    [citizen_sensor.sch, sensorsound.sch]
2019-02-06 add manf# res cap
    [citizen_sensor.sch, sensorsound.sch]
2019-02-06 BOM file .csv
    [_saved_sensorsound.sch, citizen_sensor.csv, citizen_sensor.sch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]
2019-02-06 add cap amp voltage
    [_saved_sensorsound.sch, citizen_sensor.csv, sensorsound.sch]
2019-02-06 add BOM C15
    [citizen_sensor.csv]
2019-02-06 Bom form
    [_saved_sensorsound.sch, citizen_sensor.csv]
2019-02-06 footprint c15
    [_saved_sensorsound.sch, sensorsound.sch]
2019-02-08 footprint mics4514
    [citizen_sensor.sch]
2019-02-18 add css811
    [citizen_sensor.sch]
2019-02-18 voltaje divisor batt level
    [citizen_sensor.sch]
2019-02-18 PCB read net list
    [citizen_sensor.kicad_pcb, citizen_sensor.sch]
2019-02-20 Update schematic
    [_saved_sensorsound.sch, citizen_sensor.sch]
2019-02-20 PCB routed 0.1v
    [citizen_sensor.kicad_pcb]
2019-02-20 add logos
    [citizen_sensor.kicad_pcb]
2019-02-20 add logo fablab yucatan ♥️
    [citizen_sensor.kicad_pcb]
2019-02-21 Fix antenna and mounting holes
    [citizen_sensor.kicad_pcb]
2019-02-21 fix VDD y GND of TLC2272
    [_saved_sensorsound.sch, citizen_sensor.kicad_pcb, citizen_sensor.sch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]
2019-02-22 Update mic
    [citizen_sensor.sch, sensorsound.sch]
2019-02-23 Update pot
    [sensorsound.sch]
2019-02-23 Update metadata
    [sensorsound.sch]
2019-02-23 Update meta-data
    [citizen_sensor.sch]
2019-02-23 Update compnent placement and pot
    [citizen_sensor.kicad_pcb]
2019-02-24 fabcity logo
    [citizen_sensor.kicad_pcb]
2019-02-25 Change corners
    [citizen_sensor.kicad_pcb]
2019-02-25 Change On LED
    [citizen_sensor.kicad_pcb]
2019-02-25 Update components 3d
    [citizen_sensor.kicad_pcb]
2019-02-25 Add 3D models
    [629105150521 (rev1).stp, MICS-4514.STEP, User Library-Johnson Components SMA - 50 Ohm Connectors 142-0701-801.STEP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]
2019-02-28 Auto stash before merge of "master" and "origin/master"
    change resistor mics co
    [citizen_sensor.sch, sensorsound.sch]
2019-03-20 mover resistor to layer
2019-03-20 Revert "mover resistor to layer"
    This reverts commit 3cd94dc54691067b571b78a8cbe4544d7b6d2027.
2019-03-22 example read sensor css811
2019-03-28 Add ccs and MICS sensors
2019-04-02 change equations sensor MICS
2019-04-05 add sensor uv to lpp library
2019-04-10 serial print UV delete
2019-05-03 add read sound sensor
2019-05-17 add label sheet
    [citizen_sensor.sch, sensorsound.sch]
2019-06-10 add led builtin
    [citizen_sensor.sch]
2019-06-10 add led builtin en PCB
    [citizen_sensor.kicad_pcb]
2019-06-10 Add V0.1 text
    [citizen_sensor.kicad_pcb]
2020-02-22 Update Kicad5 and fix RESET CSS811
    [citizen_sensor.kicad_pcb, citizen_sensor.sch, sensorsound.sch]
2020-02-22 best comment CSS811 error
    [firmware_citizen.ino]
2020-02-22 add read battery
2020-02-25 change battery to analoginput
2020-02-27 Fix Battery analogInput
2022-05-14 add gitignore backups kicad
2022-05-14 update kicad 6
    [citizen_sensor.kicad_pcb, citizen_sensor.kicad_sch, sensorsound.kicad_sch]
